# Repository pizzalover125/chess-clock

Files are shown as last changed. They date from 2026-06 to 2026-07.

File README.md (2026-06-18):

# clk


clk is a open source chess clock that is comparable to closed source alternative

### why clk?

if you google open source chess clock, here's the result you'll get (SOURCE: https://github.com/zabackary/open-chess-clock). it's a cool project, but i wanted to make something better. something that looks like an industry giant made it. thats why i build clk. 



### wiring diagram

The wiring diagram was made using Adafruit documentation and drawn in Excalidraw. 



### CAD

The CAD was made fully using Onshape. You can view the project using this link: https://cad.onshape.com/documents/edd4a6e5aaa49bd549f92b3e/w/95eb79d6660188d253382b5a/e/2ad3cad4f16c0b71a679224d. 






### firmware

you can find the firmware in firmware.py. it is made using CircuitPython and Adafruit's library for their i2c 7-segment display. 

### bill of materials

a detailed bill of materials can be viewed here: https://docs.google.com/spreadsheets/d/1HJi_SoZmRUPXIg3fWTzNNd4LjoeZRIxf5KhnIGp8wuw/edit?gid=0#gid=0

### credits

big thanks to Hack Club and the Stardance program for helping fund this project and providing a lot of support!

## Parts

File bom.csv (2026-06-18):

Item | Price | Link | Orders
10x MX Blue Switches | 5.99 | https://www.amazon.com/gp/product/B0G57Q1HYY?smid=A2U3R73MNHPWPS | Amazon | 6.54
2x 0.56" 4-Digit 7-Segment Display w/I2C Backpack | 11.95 | https://www.microcenter.com/product/656496/056%22_4-Digit_7-Segment_Display_w-I2C_Backpack_-_Blue | Micro Center | 47.82
22 AWG Wire | 9.99 | https://www.microcenter.com/product/456250/Hook-Up_Wire_Spool_Set_(22AWG_Solid_Core_-_25_ft)
Wire Stripper | 6.99 | https://www.microcenter.com/product/420650/eclipse-enterprise-wire-stripper-for-awg-30-20 | Notes
Screws | 0.00 | In closet | The BOM on right is w/o taxes + shipping
Raspberry Pi Pico USB-C Clone | 0.00 | Spare from another project | The Orders on left is w/ taxes and shipping
3D Printed Keycaps | 0.00 | 3d printer at home | Prime shipping on Amazon to make shipping free
3D Printed Enclosure | 0.00 | 3d printer at home
3 x AA Battery Holder | 3.99 | https://www.microcenter.com/product/474398/adafruit-industries-3-x-aa-battery-holder-with-on-off-switch | Total | 54.36

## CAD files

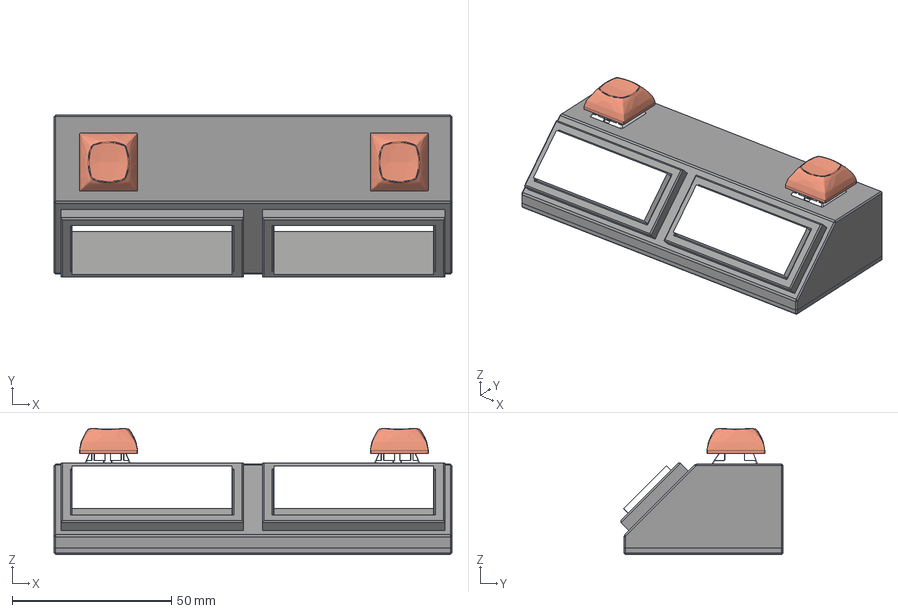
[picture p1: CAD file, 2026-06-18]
CAD/assembly.step
125.0 x 50.9 x 39.6 mm
SOP28_300mil v1 x 58
PCB x 2
LED Module x 30
Bottom x 2
Pulsador x 2
MX Mount v1 x 2
DSA V4 1x1 v4 x 2
Pieza5^Cherry MX x 2
Pin2 x 2
Top x 2
Pin1 x 2

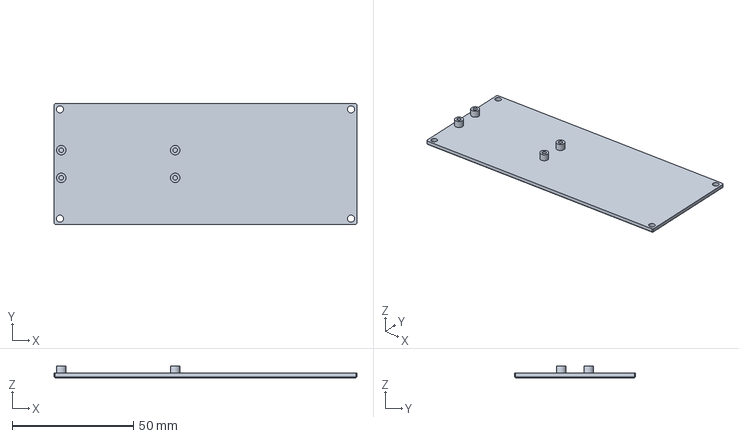
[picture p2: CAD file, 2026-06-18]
CAD/bottom-plate.step
125.0 x 50.0 x 5.00 mm

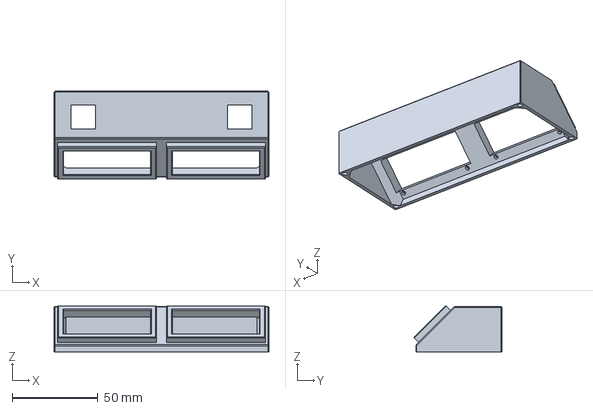
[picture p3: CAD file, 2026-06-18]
CAD/top-enclosure.step
125.0 x 50.9 x 26.7 mm

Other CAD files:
CAD/bottom-plate.stl
CAD/top-enclosure.stl

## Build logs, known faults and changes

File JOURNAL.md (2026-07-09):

# Journal

total time spent: 12 hours 10 minutes

### May 15: (60 min)
- thought of this project a long time ago
- i wanted to build an open source chess clock
- then I thought, why make the chess clock also work as a rubiks cube timer?
- thats when this idea popped in my head
- going to make this basic and cheap, so a 4 point project
- start off w schematic
- added xiao from https://hackpad.hackclub.com/resources
- going to be making the following thing:



- changing MCU to ESP32C3 bc i can create web app for chess clock!
- using low-profile switches to potentially make this folding
- finished schematic



- assigned footprints
- looked at 0.96" OLED on my desk and realized two numbers would be too small on that
- was thinking about 2 OLEDs but the Xiao has 1 i2c bus only
- guess we are switching to Pi Pico
- choc v2 switches have same travel distance but 4mm lower height than gateron
- did some research; choosing kalih PG1350



- time to route



- ez routing
- had them flipped; had to route again
- added 3d models!
- ok im not going to make it round so its easier to CAD
- mounting holes took forever for some reason but I got it!



- created logo

text-1778898806176

- tried to add texture but it didn't end up working
- ok i just realized the way i envisioned it is completely wrong
- i think i'll switch this to a cubing timer cause this is the proper thing for that

# 5/15 part 2: 45 minutes
- wanted to build cubing timer in person cause i have all the parts!
- finished placing and wiring super quickly

[will add image here; took photo on phone]

- will vibecode software something up super fast
- ok code generated but i don't have a cable; let me look for one
- found cable
- tried on my Microsoft Surface; didn't work
- tried another cable
- tried to connect to Mac; didn't work
- idk this is so weird; i've tried 2 different cables, 2 different OSes, and 3 different Picos and it never shows up on the computer.
- ok turns out the cables are power-only; not data; i need to buy a new cable
- oh well, will try tomorrow

# 5/16: 55 minutes
- okay i tried a THIRD cable and it STILL DOESN'T WORK
- I need to buy another cable later
- I'll work on PCB
- finished w schematic bc its super ez
- i want to use 1.3" OLED cause its bigger so easier to see
- downloaded the footprint + schematic from SNAPEDA
- updated schematic



- idk where to put MCU
- if I put it under then OLED pins would hit the MCU
- ok someone told me I can put it under
- found 3D model of OLED in GrabCAD and imported it
- downloaded Xiao RP2040 model from GrabCAD and imported it
- routed everything
- was going to move the mounting holes but decided not to
- ONSHAPE time!



- nvm, i wanted to change it just to be safe
  


- rounded the corners and routed! now time for CAD



- added holes + the rectangle itself



- tried to add top plate but i think its better to just have backplate
- printed the PCB IRL!
- going to print the backplate to get a feel on what this is going to be like



- prined backplate out; pretty good fit!

### 5/23: 1 hour
- time for The Great Reset
- im starting over designs
- i want to rival the industry standard cubing timer
- browsing https://speedcubeshop.com/collections/timers-mats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 for inspo + ideas
- bro no way there is an AI speedcubing timer; this is wild
- ok im thinking to use capacitve touch pad instead of switches to not make this a hackpad
- watching https://www.youtube.com/watch?v=tTMsbL0eH_M to learn
- that video wasn't helpful; watching https://www.youtube.com/watch?v=42jUcqwKIw8
- that vid didn't have much so watching this https://www.youtube.com/watch?v=mWR9Q_pTagw
- ok capacitve touch is very hard to implement in such a large area such as a palm
- lots of chance for missed calls
- did some research and a grand total of 0 people have made an open source cubing timer
- soooo this is the first! thats kind of cool



- okay i might use this type of design with infared/distance sensors on each side to determine
- mx switches aren't good bc they are designed for fingers, not hands
- ok this is a hard project
- wait i found [https://github.com/amadensor/cube-timer/tree/main/pcb/cube_timer](https://github.com/tibordp/cube-timer)
- ok mine is the first PCB + case; the project is just an ESP32 on a breadboard
- going to read https://ww1.microchip.com/downloads/en/DeviceDoc/40001946A.pdf
- ok idk if this is possible even 

### Jun 10 (2.5 hours)
- rebranding this to be a chess clock again
- planning to use 8-segment clock displays like this one:



- thats what these clocks use:



- going to also use mx switches cause hey are used in:



- time to import all CAD models
- ah i can only find 1.2" not 0.56"
- i imported the mx switch
- time to decide what MCU
- i think ill use RP2040-zero
- wait nvm its hard to mount?
- i might use pico just because its easier to mount
- imported the pico!
- apparently i need beveled face to make it have good viewing angles
- watching https://www.youtube.com/watch?v=eApyyNPppaY



- starting to look like a chess clock!
- did some more research on how to mount a mx switch
- i need a 14x14mm cutout with 1.5mm plate size



- looks great!
- ill add pico mounting now



- okay turns out every OLED is different
- so ig ill have to redo some dimensions
- also i might make it bigger

- ok found models for the 0.56 i2c 7-segment display!
- going to use that because its better



- using this image
- annoying i need to covnert to mm



- voila!
- time to add screen cutout



- looks like a chess clock
- will later figure out how to assemble

### Jun 15 (3 hours)
- i was away from my house for a couple of days
- time to get back on this project



- added tolerances



- added a border!
- it looks kinda weird ngl



- added keycaps and colors! looks very cool



- made it assembleable



- remade the assembly
- ill make a render cause why not
- technically i am done with the CAD
- but idk if i want to make a PCB
- cause it needs to arrive in time



- ok made that
- apparently M1 screws don't work with 3d printed stuff
- so ill need M2
- made it M2
- ok im working super slow now idk why

- new session at night
- i added chamfer to add M3 holes!



- the only major thing left other than firmware is how im going to assemble this
- i dont want to make a PCB cause i want it to be done in time
- PCB also not required?
- i could use a breadboard
- ok ill figure this out tmrw
- will create wiring diagram!



- kinda basic because wiring diagram is kinda basic

### Jun 16: (2 hours)
- okay i learned that expedited shipping is allowed for JLCPCB
- so im designing a PCB
- this is also due to the fact that idk how to wire it without a PCB
- will make it a lot cleaner also!



- schematic done
- time to assign footprints
- assigned them!
- problem: stemma qt is very small and hard to solder it seems like
- ok this PCB is wayyyy too simple to need a PCB at all
- ill figure out how standoffs work
- watching https://www.youtube.com/watch?v=NHIrTtLCnEo



- that was so easy
- found these bumpers: https://www.adafruit.com/product/550
- will add them
- actually no point in adding to CAD
- made this https://docs.google.com/spreadsheets/d/1HJi_SoZmRUPXIg3fWTzNNd4LjoeZRIxf5KhnIGp8wuw/edit?usp=sharing!
- comes out to $54.36 at a quantity of 1
- hardware is so expensive
- ok i just need to make firmware
- i think this project is almost ready to ship!







- added these holes:



### Jun 17: 1 hour
- going to work on the firmware
- somebody told me that the M2 wouldn't work
- ok this is the firmware: https://pastebin.com/s5BTVMHb
- pretty simple
- going to make it better when i get parts
- redesigned the wiring diagram cause I'm going to have batteries!



- the display uses M2.5 holes 😭
- time to fix
- fixed
- going to work on README
- created README
- updated files

# BUILD

### jun 29 (1 hour)
- ok this is going to be hard to build
- I LAPSEd me soldering the 7-segment display
- i printed out the bottom part
- realized the top part isn't compatible with bottom part
- need to redesign
- didn't have USB-C hole either
- redesigned!
- asked for help on Slack
- got that help with print settings
- ok redesigned:



- printed it
- the hole was too small
- the supports were impossible to remove
- will reprint

### july 9th (1 hour)
- i was a bit sidetracked from this project
- time to lock in and actually build it :)
- i got these stemma qt ports to make assembly easier
- soldered wires to the mx switches
- i cant find the pink usb-c pi pico
- i've looked off-jounral on multiple days
- AHHHHH
- found it
- LETS GO
- soldered the wires
- assembled it on a breadboard
- wow that took a while

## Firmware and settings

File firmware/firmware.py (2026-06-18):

from machine import Pin, I2C
import time
from adafruit_ht16k33.segments import Seg7x4
 
i2c = I2C(0, sda=Pin(0), scl=Pin(1), freq=400000)
display = Seg7x4(i2c)
 
left_button = Pin(4, Pin.IN, Pin.PULL_UP)
right_button = Pin(5, Pin.IN, Pin.PULL_UP)
 
left_time = 180000
right_time = 180000
 
active = None
 
last_update = time.ticks_ms()
last_left_press = 0
last_right_press = 0
 
def fmt(ms):
    if ms < 0:
        ms = 0
    s = ms // 1000
    return f"{s // 60:02d}{s % 60:02d}"
 
while True:
    now = time.ticks_ms()
    elapsed = time.ticks_diff(now, last_update)
    last_update = now
 
    if active == 0:
        left_time -= elapsed
        if left_time <= 0:
            left_time = 0
            active = None
 
    elif active == 1:
        right_time -= elapsed
        if right_time <= 0:
            right_time = 0
            active = None
 
    if not left_button.value():
        if time.ticks_diff(now, last_left_press) > 200:
            last_left_press = now
            if active is None:
                active = 1
            elif active == 0:
                active = 1
 
    if not right_button.value():
        if time.ticks_diff(now, last_right_press) > 200:
            last_right_press = now
            if active is None:
                active = 0
            elif active == 1:
                active = 0
 
    if active == 0:
        display.print(fmt(left_time))
    elif active == 1:
        display.print(fmt(right_time))
    else:
        display.print(fmt(left_time))
 
    display.colon = True
    time.sleep_ms(10)

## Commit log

2026-05-16 Add project journal entries for May 15
    Documented the development process and design decisions for an open-source chess clock and Rubik's cube timer project, including schematic creation, component selection, and routing.
2026-05-16 Revise journal entries and project updates
    Updated journal entries with new timings and progress on cubing timer project, including schematic updates and PCB routing.
2026-06-18 added CAD files
    [assembly.step, bottom-plate.step, bottom-plate.stl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]
